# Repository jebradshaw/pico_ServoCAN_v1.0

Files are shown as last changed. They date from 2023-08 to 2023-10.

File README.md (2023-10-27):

# pico_ServoCAN_v1.0
RasPi Pico RP2040 Sevo CAN Microcontroller Board

RP2040_pico_ServoCAN Gimp picture

This RasPi Pico RP2040 microcontroller board contains an MCP2515 SPI CAN bus transceiver and driver electronics, GPIO accessible ports, an I2C port with STEMMA and JST-XH connectors, two power FET driver ports, an on board 5 volt 2 amp DC-DC switching power supply, a TTL level serial UART, and jumper options.

Note that on version 1.0, the MCP2515 18-pin DIP package needs pin 17 (!RESET) tied high, usuaally through a solder jumper from pin 17 to pin 18 (Vcc) on the underside of the PCB.
  Also pin 8 (STBY) of the MCP2561 CAN transceiver should be tied LOW to ground through an external wire jumper.
  
Solder_jumpers_backOfBoard_Marked

Also note that the board was originally designed using an OKI 78SR Series 5V 1.5A regulator (U4), which are now very difficult to come by.  So the part has been replaced with a VR20S05 5 volt 2 amp regulator which comes in a slightly larger, sealed, package (available from Digikey - https://www.xppower.com/portals/0/pdfs/SF_VR20.pdf).  To get this regulator to fit on the board, C6 (a .1uF capacitor) should not be soldered in place.

KiCAD_PCB_Artwork

3D_Render_of_PCB

KiCAD 3D render of PCB

Schamatic

Schematic (PDF format) - [pico_Kingfisher_2023.pdf](https://github.com/jebradshaw/pico_ServoCAN_v1.0/files/12242137/pico_Kingfisher_2023.pdf)

  If using Adafruits Circuit Python (which I like for the RP2040), copy the lib folder contents to the pico drive under .lib to include the CAN libraries for the CAN bus controller.  An example program to test the CAN transmit and receive functionality is also included.

  Also added is an Arduino (which I also really like) sketch for the CAN interface and servo outs running on both cores overclocked to 250MHz (Core Temp ~ 31 deg C).

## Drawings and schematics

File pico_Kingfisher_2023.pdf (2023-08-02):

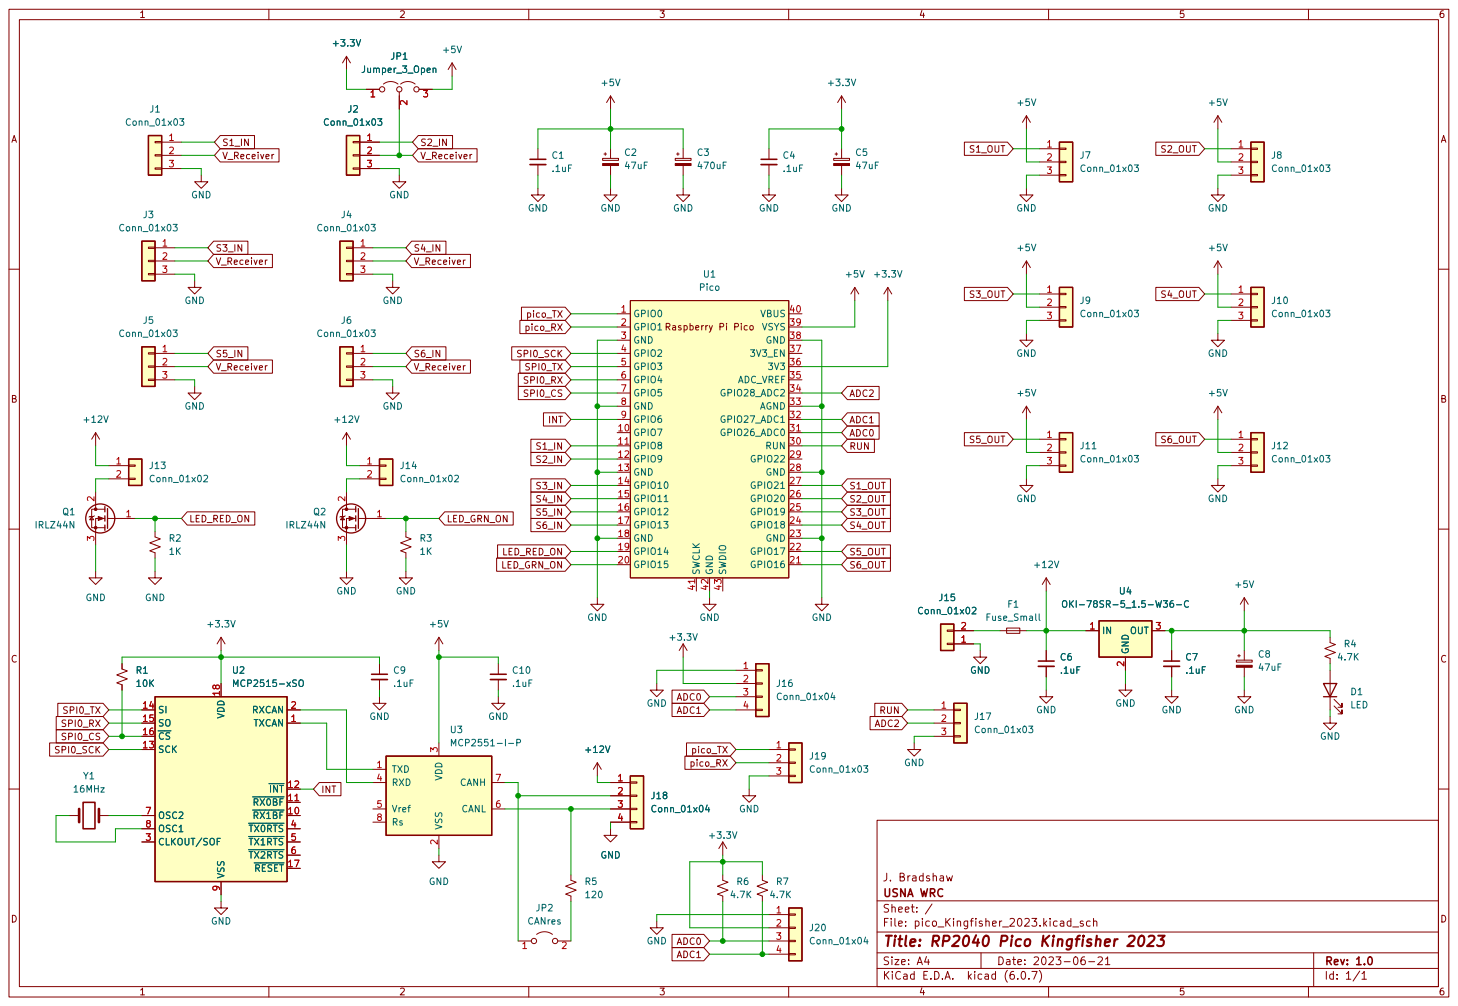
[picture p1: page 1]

3 RXD 4 Vref 5 CANL 6 CANH 7 Rs 8 U3MCP2551-I-PC10

J. Bradshaw
File: pico_Kingfisher_2023.kicad_sch Sheet: / USNA WRC

Id: 1/1 Title: RP2040 Pico Kingfisher 2023

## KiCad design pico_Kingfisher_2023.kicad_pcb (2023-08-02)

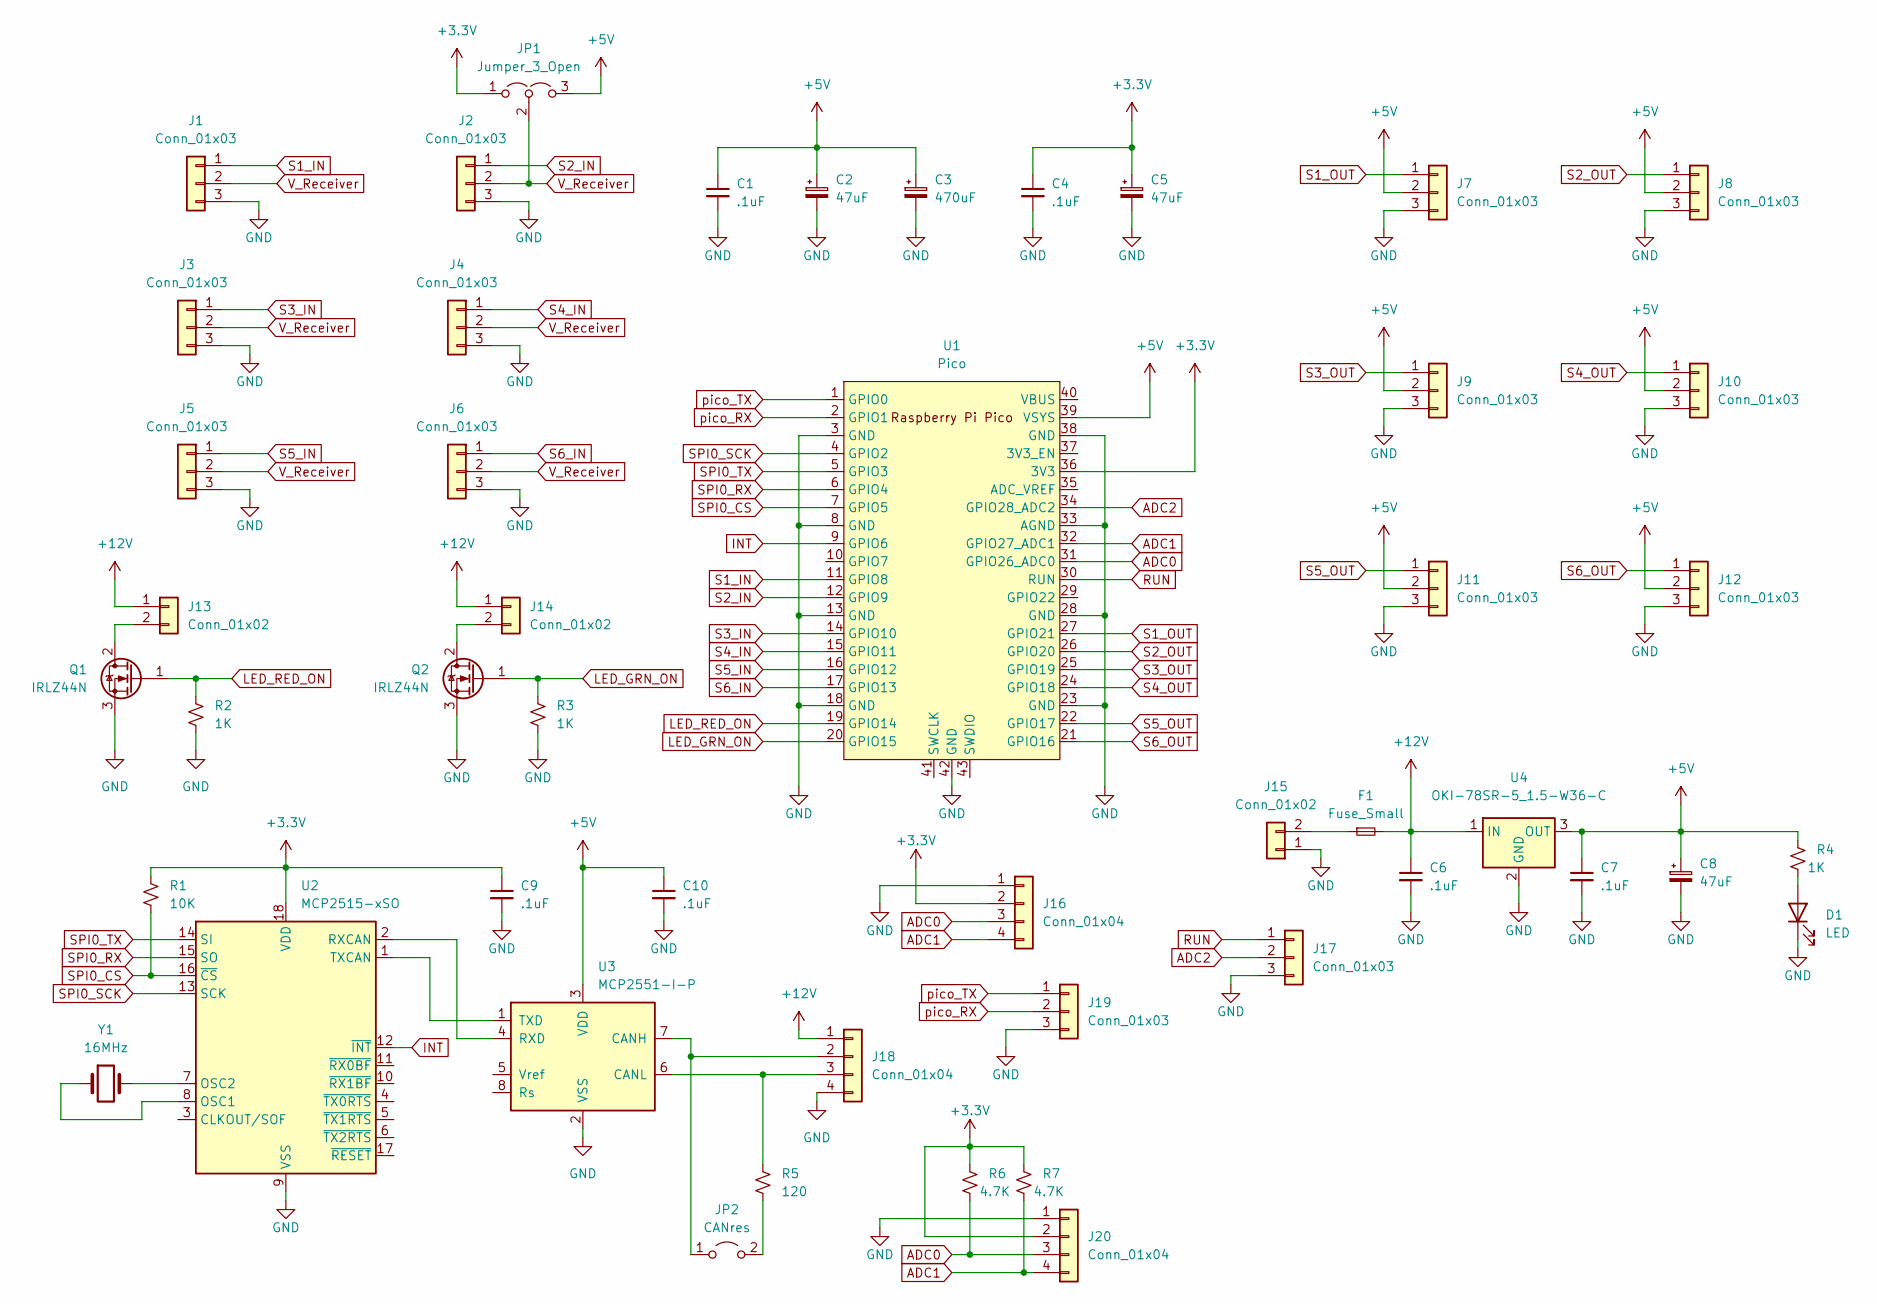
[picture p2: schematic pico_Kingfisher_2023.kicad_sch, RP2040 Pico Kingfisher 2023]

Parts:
C1, C4, C6, C7, C9, C10: .1uF; C_Disc_D5.0mm_W2.5mm_P2.50mm
C2, C5, C8: 47uF; CP_Radial_D5.0mm_P2.50mm
C3: 470uF; CP_Radial_D5.0mm_P2.50mm
D1: LED; LED_D3.0mm
F1: Fuse_Small; Fuse_Littelfuse_395Series
J1, J2, J3, J4, J5, J6, J7, J8, J9, J10, J11, J12, J19: Conn_01x03; PinHeader_1x03_P2.54mm_Vertical
J13, J14, J15: Conn_01x02; JST_XH_B2B-XH-A_1x02_P2.50mm_Vertical
J16, J18: Conn_01x04; JST_XH_B4B-XH-A_1x04_P2.50mm_Vertical
J17: Conn_01x03; JST_XH_B3B-XH-A_1x03_P2.50mm_Vertical
J20: Conn_01x04; JST_SH_SM04B-SRSS-TB_1x04-1MP_P1.00mm_Horizontal
JP1: Jumper_3_Open; PinHeader_1x03_P2.54mm_Vertical
JP2: CANres; PinHeader_1x02_P2.54mm_Vertical
Q1, Q2: IRLZ44N; TO-220-3_Horizontal_TabDown
R1: 10K; R_Axial_DIN0204_L3.6mm_D1.6mm_P7.62mm_Horizontal
R2, R3, R4: 1K; R_Axial_DIN0204_L3.6mm_D1.6mm_P7.62mm_Horizontal
R5: 120; R_Axial_DIN0204_L3.6mm_D1.6mm_P7.62mm_Horizontal
R6, R7: 4.7K; R_Axial_DIN0204_L3.6mm_D1.6mm_P7.62mm_Horizontal
U1: Pico; RPi_Pico_SMD_TH
U2: MCP2515-xSO; DIP-18_W7.62mm
U3: MCP2551-I-P; DIP-8_W7.62mm
U4: OKI-78SR-5_1.5-W36-C; Converter_DCDC_Murata_OKI-78SR_Vertical
Y1: 16MHz; Crystal_HC49-4H_Vertical

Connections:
+3.3V: C4.1, C5.1, C9.1, J16.2, J20.2, JP1.1 (A), R1.1, R6.1, R7.1, U1.36 (3V3), U2.18 (VDD)
+5V: C1.1, C2.1, C3.1, C7.1, C8.1, C10.1, J7.2, J8.2, J9.2, J10.2, J11.2, J12.2, JP1.3 (B), R4.1, U1.39 (VSYS), U3.3 (VDD), U4.3 (OUT)
+12V: C6.1, F1.2, J13.1, J14.1, J18.1, U4.1 (IN)
ADC0: J16.3, J20.3, R6.2, U1.31 (GPIO26_ADC0)
ADC1: J16.4, J20.4, R7.2, U1.32 (GPIO27_ADC1)
ADC2: J17.2, U1.34 (GPIO28_ADC2)
GND: C1.2, C2.2, C3.2, C4.2, C5.2, C6.2, C7.2, C8.2, C9.2, C10.2, D1.1 (K), J1.3, J2.3, J3.3, J4.3, J5.3, J6.3, J7.3, J8.3, J9.3, J10.3, J11.3, J12.3, J15.1, J16.1, J17.3, J18.4, J19.3, J20.1, Q1.3 (S), Q2.3 (S), R2.2, R3.2, U1.3 (GND), U1.8 (GND), U1.13 (GND), U1.18 (GND), U1.23 (GND), U1.28 (GND), U1.33 (AGND), U1.38 (GND), U1.42 (GND), U2.9 (VSS), U3.2 (VSS), U4.2 (GND)
INT: U1.9 (GPIO6), U2.12 (~INT)
LED_GRN_ON: Q2.1 (G), R3.1, U1.20 (GPIO15)
LED_RED_ON: Q1.1 (G), R2.1, U1.19 (GPIO14)
unnamed: J13.2, Q1.2 (D)
unnamed: J14.2, Q2.2 (D)
unnamed: F1.1, J15.2
unnamed: J18.2, JP2.1 (A), U3.7 (CANH)
unnamed: J18.3, R5.1, U3.6 (CANL)
unnamed: JP2.2 (B), R5.2
unnamed: D1.2 (A), R4.2
unnamed: U2.1 (TXCAN), U3.1 (TXD)
unnamed: U2.2 (RXCAN), U3.4 (RXD)
unnamed: U2.7 (OSC2), Y1.2
unnamed: U2.8 (OSC1), Y1.1
RUN: J17.1, U1.30 (RUN)
S1_IN: J1.1, U1.11 (GPIO8)
S1_OUT: J7.1, U1.27 (GPIO21)
S2_IN: J2.1, U1.12 (GPIO9)
S2_OUT: J8.1, U1.26 (GPIO20)
S3_IN: J3.1, U1.14 (GPIO10)
S3_OUT: J9.1, U1.25 (GPIO19)
S4_IN: J4.1, U1.15 (GPIO11)
S4_OUT: J10.1, U1.24 (GPIO18)
S5_IN: J5.1, U1.16 (GPIO12)
S5_OUT: J11.1, U1.22 (GPIO17)
S6_IN: J6.1, U1.17 (GPIO13)
S6_OUT: J12.1, U1.21 (GPIO16)
SPI0_CS: R1.2, U1.7 (GPIO5), U2.16 (~CS)
SPI0_RX: U1.6 (GPIO4), U2.15 (SO)
SPI0_SCK: U1.4 (GPIO2), U2.13 (SCK)
SPI0_TX: U1.5 (GPIO3), U2.14 (SI)
V_Receiver: J1.2, J2.2, J3.2, J4.2, J5.2, J6.2, JP1.2 (C)
pico_RX: J19.2, U1.2 (GPIO1)
pico_TX: J19.1, U1.1 (GPIO0)

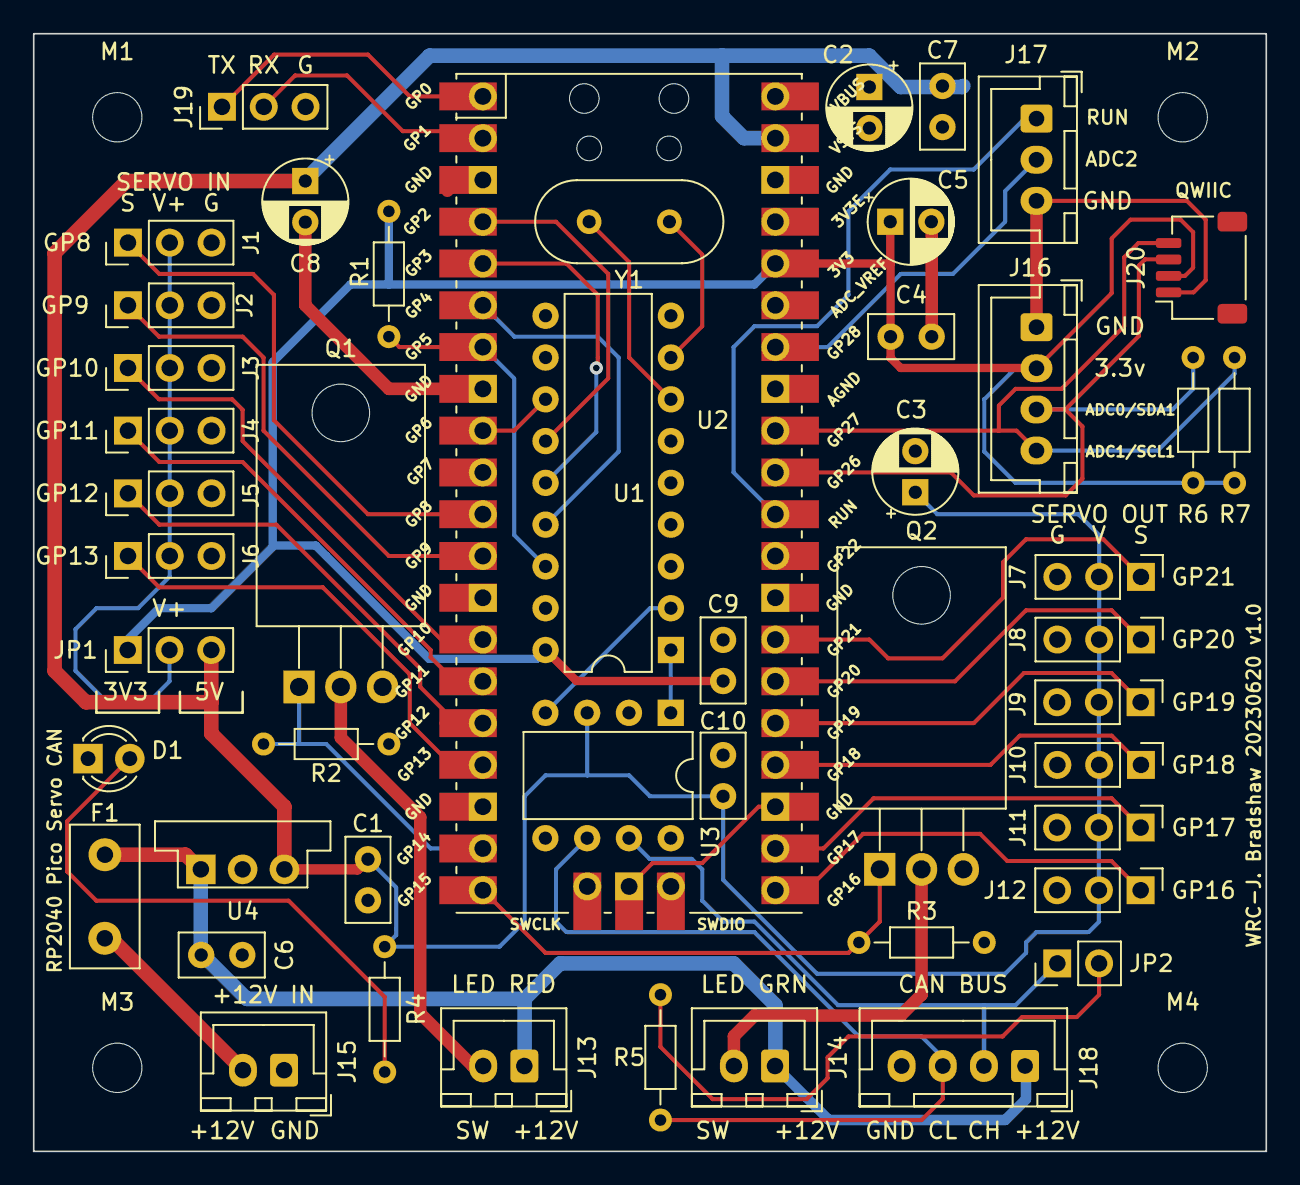
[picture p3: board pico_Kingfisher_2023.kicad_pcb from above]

Board: 2 copper layers, 74.9 x 67.9 mm, 52 parts (0 on the bottom side), 41 nets.

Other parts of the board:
M1, M2, M3, M4: MountingHole_3mm

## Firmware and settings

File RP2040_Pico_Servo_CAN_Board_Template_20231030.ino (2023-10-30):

// RP2040 Pico Servo CAM board Arduino Sketch Template
// J. Bradshaw 20231027
// Overclocked to 250MHz processor clock (core temp of ~31 deg C)

#include <Wire.h>
#include <mcp_can.h>
#include <mcp_can_dfs.h>
#include <SPI.h>              // RasPi Pico uses RX(4), CSn(5), SCK(2), and TX(3)
#include <Servo.h>

// Servo Pulse Input channels
const int servoInPin1 = 8;      // capture input servo pulse 1
const int servoInPin2 = 9;      // capture input servo pulse 2
const int servoInPin3 = 10;      // capture input servo pulse 3
const int servoInPin4 = 11;      // capture input servo pulse 4
const int servoInPin5 = 12;      // capture input servo pulse 5
const int servoInPin6 = 13;      // capture input servo pulse 6

// CAN defines and variables
#define MY_CAN_ID 0x1234ABCD

#define SPI_CS_PIN 5      // GP5 is default CS
#define CAN_INT_PIN 6     // GP6 is default Interrupt in pin

MCP_CAN can(SPI_CS_PIN); // Set CS pin

unsigned char can_flagRecv = 0;
unsigned char can_rxBufLen = 0;
unsigned char can_rx_buf[8];
unsigned long can_rxId = 0;

unsigned long can_txId = MY_CAN_ID; // 
unsigned char can_txBufLen = 0;
unsigned char can_tx_buf[8] = {0, 0, 0, 0, 0, 0, 0, 0};

static unsigned long can_millisLastTx1 = 0;

int led = LED_BUILTIN; // the PWM pin the LED is attached to
int brightness = 0;    // how bright the LED is
int fadeAmount = 20;    // how many points to fade the LED by
unsigned long tm;  // Used to capture millis() timestamp

Servo servo1;  // create servo object to control a servo
Servo servo2;  // create servo object to control a servo
Servo servo3;  // create servo object to control a servo
Servo servo4;  // create servo object to control a servo
Servo servo5;  // create servo object to control a servo
Servo servo6;  // create servo object to control a servo

int SERVO_MIN = 750;
int SERVO_MAX = 2250;
int SERVO_CENT = (SERVO_MIN + SERVO_MAX) / 2;
int SERVO_SPAN = (SERVO_MAX - SERVO_MIN);


static unsigned long servoPulse1 = 0;
static unsigned long servoPulse2 = 0;
static unsigned long servoPulse3 = 0;
static unsigned long servoPulse4 = 0;
static unsigned long servoPulse5 = 0;
static unsigned long servoPulse6 = 0;

//variables for capturing servo 1 pulse
int sv1_usTimeTemp;
int sv1_usTime = 0;

void servo1_cap(){
  if(digitalRead(servoInPin1) == HIGH){
    sv1_usTimeTemp = micros();    //capture current us_timer
  }
  else{
    sv1_usTime = micros() - sv1_usTimeTemp;   //take difference between time capture values        
  }
}

//variables for capturing servo 2 pulse
int sv2_usTimeTemp;
int sv2_usTime = 0;

void servo2_cap(){
  if(digitalRead(servoInPin2) == HIGH){
    sv2_usTimeTemp = micros();    //capture current us_timer        
  }
  else{
    sv2_usTime = micros() - sv2_usTimeTemp;   //take difference between time capture values        
  }
}

//variables for capturing servo 3 pulse
int sv3_usTimeTemp;
int sv3_usTime = 0;

void servo3_cap(){
  if(digitalRead(servoInPin3) == HIGH){
    sv3_usTimeTemp = micros();    //capture current us_timer        
  }
  else{
    sv3_usTime = micros() - sv3_usTimeTemp;   //take difference between time capture values        
  }
}

//variables for capturing servo 4 pulse
int sv4_usTimeTemp;
int sv4_usTime = 0;

void servo4_cap(){
  if(digitalRead(servoInPin4) == HIGH){
    sv4_usTimeTemp = micros();    //capture current us_timer        
  }
  else{
    sv4_usTime = micros() - sv4_usTimeTemp;   //take difference between time capture values        
  }
}

//variables for capturing servo 5 pulse
int sv5_usTimeTemp;
int sv5_usTime = 0;

void servo5_cap(){
  if(digitalRead(servoInPin5) == HIGH){
    sv5_usTimeTemp = micros();    //capture current us_timer        
  }
  else{
    sv5_usTime = micros() - sv5_usTimeTemp;   //take difference between time capture values        
  }
}

//variables for capturing servo 6 pulse
int sv6_usTimeTemp;
int sv6_usTime = 0;

void servo6_cap(){
  if(digitalRead(servoInPin6) == HIGH){
    sv6_usTimeTemp = micros();    //capture current us_timer        
  }
  else{
    sv6_usTime = micros() - sv6_usTimeTemp;   //take difference between time capture values        
  }
}

void setup() {
    
  delay(100); // short delay upon startup for voltages to settle on IMU and Xbee

  // Initialize I2C bus
  Wire1.setSDA(26); // set pins for I2C1_SCL (GP27) and I2C1_SDA (GP26)
  Wire1.setSCL(27);
  Wire1.begin();

  // Serial is the USB Interface
  Serial.begin(115200); // USB Interface by default (no need to define pins here)
  
  // Initialize Serial 1 (UART0 !!)  on pin GP0 (TX) and pin GP1 (RX)
  pinMode(0,OUTPUT);  // pin 0 is TX UART0
  pinMode(1,INPUT);   // pin 1 is RX UART0
  Serial1.setTX(0);
  Serial1.setRX(1);   
  Serial1.begin(115200);

  // Setup CAN SPI bus for MCP2515 CAN Controller IC
  SPI.setSCK(2);
  SPI.setTX(3);
  SPI.setRX(4);  
  SPI.setCS(5);

  // Initialize MCP2515 running at 16MHz with a baudrate of 250kb/s and the masks and filters disabled.
  if(can.begin(MCP_ANY, CAN_250KBPS, MCP_16MHZ) == CAN_OK)
    Serial.println("MCP2515 Initialized Successfully!");
  else
    Serial.println("Error Initializing MCP2515...");
  
  can.setMode(MCP_NORMAL);   // Set operation mode to normal so the MCP2515 sends acks to received data.

  pinMode(CAN_INT_PIN, INPUT);  // Configuring pin for /INT input
  //attachInterrupt(CAN_INT_PIN, MCP2515_ISR, FALLING); // start interrupt
 
}

void setup1() {
    // Initialize the led
  pinMode(led, OUTPUT);
  digitalWrite(led, HIGH);

  servo1.attach(16, SERVO_MIN, SERVO_MAX);  // attaches the servo on GPIO_16 to the servo object
  servo2.attach(17, SERVO_MIN, SERVO_MAX);  // attaches the servo on GPIO_17 to the servo object
  servo3.attach(18, SERVO_MIN, SERVO_MAX);  // attaches the servo on GPIO_18 to the servo object
  servo4.attach(19, SERVO_MIN, SERVO_MAX);  // attaches the servo on GPIO_19 to the servo object
  servo5.attach(20, SERVO_MIN, SERVO_MAX);  // attaches the servo on GPIO_20 to the servo object
  servo6.attach(21, SERVO_MIN, SERVO_MAX);  // attaches the servo on GPIO_21 to the servo object

//Create the Servo pulse input objects  
  pinMode(servoInPin1, INPUT_PULLDOWN);
  attachInterrupt(digitalPinToInterrupt(servoInPin1), servo1_cap, CHANGE);

  pinMode(servoInPin2, INPUT_PULLDOWN);
  attachInterrupt(digitalPinToInterrupt(servoInPin2), servo2_cap, CHANGE);

  pinMode(servoInPin3, INPUT_PULLDOWN);
  attachInterrupt(digitalPinToInterrupt(servoInPin3), servo3_cap, CHANGE);

  pinMode(servoInPin4, INPUT_PULLDOWN);
  attachInterrupt(digitalPinToInterrupt(servoInPin4), servo4_cap, CHANGE);

  pinMode(servoInPin5, INPUT_PULLDOWN);
  attachInterrupt(digitalPinToInterrupt(servoInPin5), servo5_cap, CHANGE);

  pinMode(servoInPin6, INPUT_PULLDOWN);
  attachInterrupt(digitalPinToInterrupt(servoInPin6), servo6_cap, CHANGE);
}


// main loop core 0
void loop() {
  static unsigned long serial_last = 0;
  tm = millis();

  //Serial.println(tm);

  float yawPosRad = sinf(tm * .01) + 1.0/3.0;
  float pitchPosRad = sinf(tm * .01) + 2.0/3.0;
  float rollPosRad = sinf(tm * .01);
  
  // check if a CAN receive Interrupt has occured
  if(CAN_MSGAVAIL == can.checkReceive()) {
    can_flagRecv = 1;
    // read data,  len: data length, buf: data buf
    can.readMsgBuf(&can_rxId, &can_rxBufLen, can_rx_buf);
  }
    
  if (can_flagRecv) {
    // check if get data
    can_flagRecv = 0;                   // clear flag

    Serial.printf("CAN RX id=0x%5X data: ", can_rxId);
    for (int i = 0; i < can_rxBufLen; i++) {
      Serial.printf(" %2X", can_rx_buf[i]);
    }
    Serial.println();
  }// if flagRecv

  // Transmit CAN data to ID can_txId
  if(millis() > can_millisLastTx1 + 100){
    can_millisLastTx1 = millis();
    // send data:  id = 0x00, standard frame, data len = 8, can_tx_buf: data buf
      
    int yawRaw = (int)(((yawPosRad / 2.0*PI) - .5) * 65535);
    int byteLow = yawRaw & 0x00ff;
    int byteHigh = (yawRaw >> 8) & 0x00ff;
    can_tx_buf[0] = byteLow;
    can_tx_buf[1] = byteHigh;

    int pitchRaw = (int)((pitchPosRad / PI) * 65535);
    byteLow = pitchRaw & 0x00ff;
    byteHigh = (pitchRaw >> 8) & 0x00ff;
    can_tx_buf[2] = byteLow;
    can_tx_buf[3] = byteHigh;

    int rollRaw = (int)((rollPosRad / PI) * 65535);
    byteLow = rollRaw & 0x00ff;
    byteHigh = (rollRaw >> 8) & 0x00ff;
    can_tx_buf[4] = byteLow;
    can_tx_buf[5] = byteHigh;

    can_tx_buf[6] = 0;
    can_tx_buf[7] = 0;

    can_txId = MY_CAN_ID;
    can.sendMsgBuf(can_txId, 8, can_tx_buf);  // transmit the CAN data on the bus
  }  

  // serial transmit
  if(tm > serial_last + 20){
    serial_last = tm;

    Serial.printf("Core Temp: %.1fC ", analogReadTemp());
    Serial.printf("%d CAN TX id=%d data: ", millis(), can_txId);
    for(int i=0;i<8;i++){
      Serial.printf(" %2X", can_tx_buf[i]);
    }
    Serial.printf(" SVin1:%d", servoPulse1);
    Serial.printf(" SVin2:%d", servoPulse2);
    Serial.printf(" SVin3:%d", servoPulse3);
    Serial.printf(" SVin4:%d", servoPulse4);
    Serial.printf(" SVin5:%d", servoPulse5);
    Serial.printf(" SVin6:%d", servoPulse6);
    Serial.printf("\r\n");    
  }
}

//main loop for core 1
void loop1(){
  tm = millis();

  static unsigned long led_last = 0;
  static unsigned long servo1_last = 0;

  servoPulse1 = sv1_usTime; // read the last updated servo pulse 1 value
  servoPulse2 = sv2_usTime; // read the last updated servo pulse 2 value
  servoPulse3 = sv3_usTime; // read the last updated servo pulse 3 value
  servoPulse4 = sv4_usTime; // read the last updated servo pulse 4 value
  servoPulse5 = sv5_usTime; // read the last updated servo pulse 5 value
  servoPulse6 = sv6_usTime; // read the last updated servo pulse 6 value

  if(servoPulse1 > 2400)
    servoPulse1 = 0;
  if(servoPulse2 > 2400)
    servoPulse2 = 0;
  if(servoPulse3 > 2400)
    servoPulse3 = 0;
  if(servoPulse4 > 2400)
    servoPulse4 = 0;  
  if(servoPulse5 > 2400)
    servoPulse5 = 0;
  if(servoPulse6 > 2400)
    servoPulse6 = 0;
    
  // flash led to indiccate activity
  analogWrite(led, brightness);    // set the brightness
  // change the brightness for next time through the loop:
  brightness = brightness + fadeAmount;
  if (brightness <= 0 || brightness >= 255) {    // reverse the direction of the fading at the ends of the fade
    fadeAmount = -fadeAmount;
  }

  // update servo 1 every 80 milliseconds
  if(tm > servo1_last + 80){
    float scaledServoValNorm1 = sinf(tm * .005) / (PI/2.0) * 1/6;
    float scaledServoValNorm2 = sinf(tm * .005) / (PI/2.0) * 2/6;
    float scaledServoValNorm3 = sinf(tm * .005) / (PI/2.0) * 3/6;
    float scaledServoValNorm4 = sinf(tm * .005) / (PI/2.0) * 4/6;
    float scaledServoValNorm5 = sinf(tm * .005) / (PI/2.0) * 5/6;
    float scaledServoValNorm6 = sinf(tm * .005) / (PI/2.0);
  
    int servoOut_us1 = (int)(SERVO_CENT + (scaledServoValNorm1*(SERVO_SPAN/2.0)));
    int servoOut_us2 = (int)(SERVO_CENT + (scaledServoValNorm2*(SERVO_SPAN/2.0)));
    int servoOut_us3 = (int)(SERVO_CENT + (scaledServoValNorm3*(SERVO_SPAN/2.0)));
    int servoOut_us4 = (int)(SERVO_CENT + (scaledServoValNorm4*(SERVO_SPAN/2.0)));
    int servoOut_us5 = (int)(SERVO_CENT + (scaledServoValNorm5*(SERVO_SPAN/2.0)));
    int servoOut_us6 = (int)(SERVO_CENT + (scaledServoValNorm6*(SERVO_SPAN/2.0)));
    
    // servo.write(servoOut); // Used to write 'Degrees"
    servo1.writeMicroseconds(servoOut_us1);
    servo2.writeMicroseconds(servoOut_us2);
    servo3.writeMicroseconds(servoOut_us3);
    servo4.writeMicroseconds(servoOut_us4);
    servo5.writeMicroseconds(servoOut_us5);
    servo6.writeMicroseconds(servoOut_us6);
  }
  delay(20);
} // loop1

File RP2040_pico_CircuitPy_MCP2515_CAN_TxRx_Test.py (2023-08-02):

import time
import board
import busio
from digitalio import DigitalInOut
from adafruit_mcp2515.canio import Timer
from adafruit_mcp2515.canio import Message, RemoteTransmissionRequest
from adafruit_mcp2515 import MCP2515 as CAN

#CAN node ID
NODE_ID = 0x2234ABCD

# declare SPI pins for CAN MCP2515
clk_pin = board.GP2
mosi_pin = board.GP3
miso_pin = board.GP4
cs_can_pin = board.GP5

cs_can = DigitalInOut(cs_can_pin)
cs_can.switch_to_output()
spi = busio.SPI(clk_pin, mosi_pin, miso_pin)
can_bus = CAN(spi, cs_can, baudrate = 500000)#, silent=True)

t = Timer(timeout=5)
next_message = None
message_num = 0
i = 0

can_tx_time_delay = .1 # tranmit CAN message check every .1 seconds
can_tx_tm_last = 0

can_rx_time_delay = .01 # receive CAN message check every .01 seconds
can_rx_tm_last = 0

tm_display_last = 0
while True:
    tm = time.monotonic()        
    
    if tm > can_tx_tm_last + can_tx_time_delay:
        can_tx_tm_last = tm
        dataCANtx = (int(tm*1000000000)).to_bytes(8,'big', signed=False)       
#       dataCANtx = (0x004534521300AA).to_bytes(8,'big', signed=False)
        messageCANtx = Message(id=0x1234ABCD, data = dataCANtx, extended=True)        
        try:
            send_success = can_bus.send(messageCANtx)            
            text_can_rx_str = 'Txid:' + str(hex(messageCANtx.id)) + ' '
            for i in range(len(messageCANtx.data)):                        
                text_can_rx_str = text_can_rx_str + '{:x} '.format(messageCANtx.data[i])
            print('{:.2f} '.format(tm) + ' ' + text_can_rx_str)
        except:
            print("Send failure - Check for attached device!")
    
    if tm > can_rx_tm_last + can_rx_time_delay:
        with can_bus.listen() as listener:
            message_count = listener.in_waiting()
            if message_count > 0:
                for _i in range(message_count):
                    msg = listener.receive()                    
                    text_can_rx_str = 'Rxid:' + str(hex(msg.id)) + ' '
                    for i in range(len(msg.data)):                        
                        text_can_rx_str = text_can_rx_str + '{:x} '.format(msg.data[i])
                    print('{:.2f} '.format(tm) + ' ' + text_can_rx_str)
                        
